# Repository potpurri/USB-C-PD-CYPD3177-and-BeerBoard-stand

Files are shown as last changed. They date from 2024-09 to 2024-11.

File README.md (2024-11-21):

# USB Power Delivery Board (CYPD-3177) / BeerBoard-stand

**THIS IS AN OLD DESIGN, FOR VER 2 LOOK AT [THIS REPOSITORY](https://github.com/potpurri/USB-C_PD_Board_V2_CYPD3177).**

This **USB Power Delivery (PD) Board** is based around the **CYPD-3177** chipset. The board allows users to select the desired output **voltage** and **current** using onboard switches, making it ideal for powering my **breadboard projects**. [Schematic can be found here.](https://github.com/potpurri/USB-C-PD-CYPD3177-and-BeerBoard-stand/blob/f3c342192d2ab72d846928ec36ac7f8050d37a6a/imgs/Schematic.pdf)

Users can choose between the following **voltage levels**: **5V, 9V, 12V, 15V, and 20V**, and **current levels**: **1A, 2A, 3A, 4A, and 5A**, depending on the configuration and power supply capabilities.

(The underside of the board also functions as a stand for the [BeerBoard](https://github.com/potpurri/BeerBoard))

The board is soldered by me using a [Pinecil V2](https://wiki.pine64.org/wiki/Pinecil) by PINE64  and [MHP50](https://e-design.com.cn/en/Mini-Hot-Plate-Preheater-MHP50-PG9555615) by MiniWare.

## Key Features
- Based on the **CYPD-3177** USB PD controller
- User-selectable output **voltage**: **5V, 9V, 12V, 15V, and 20V**
- User-selectable output **current**: **1A, 2A, 3A, 4A, and 5A**
- Supports standard USB Power Delivery profiles for flexible power output; compact and versatile

## Images

### Assembled Images
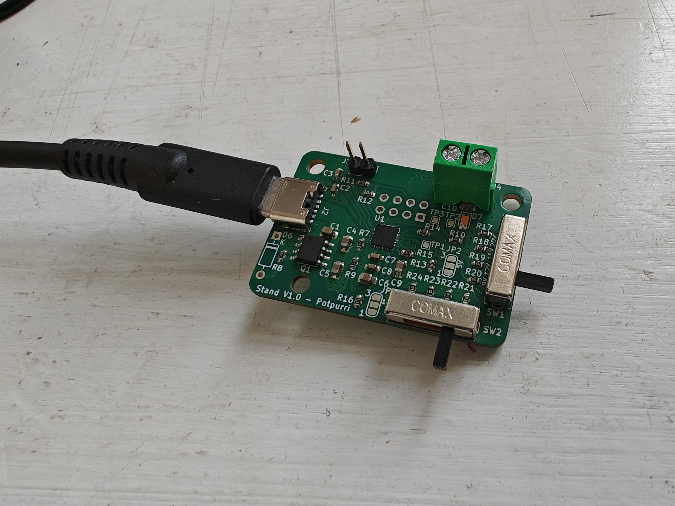
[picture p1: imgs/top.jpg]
USB PD Board

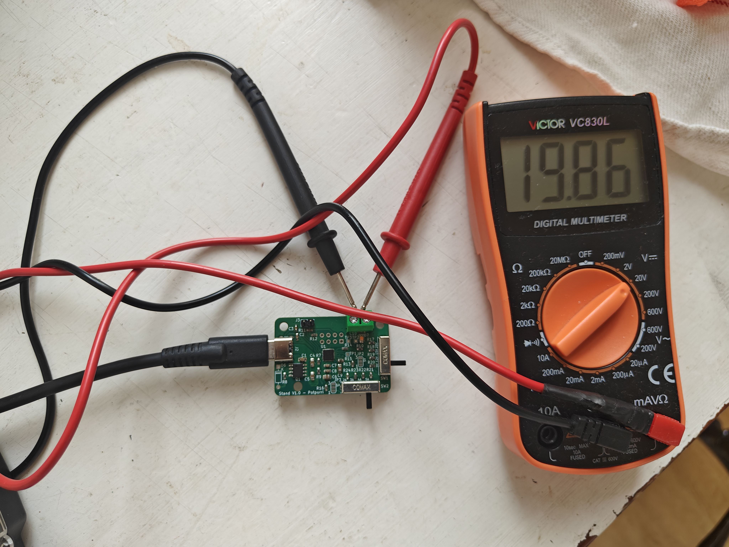
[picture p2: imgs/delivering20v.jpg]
20V delivery

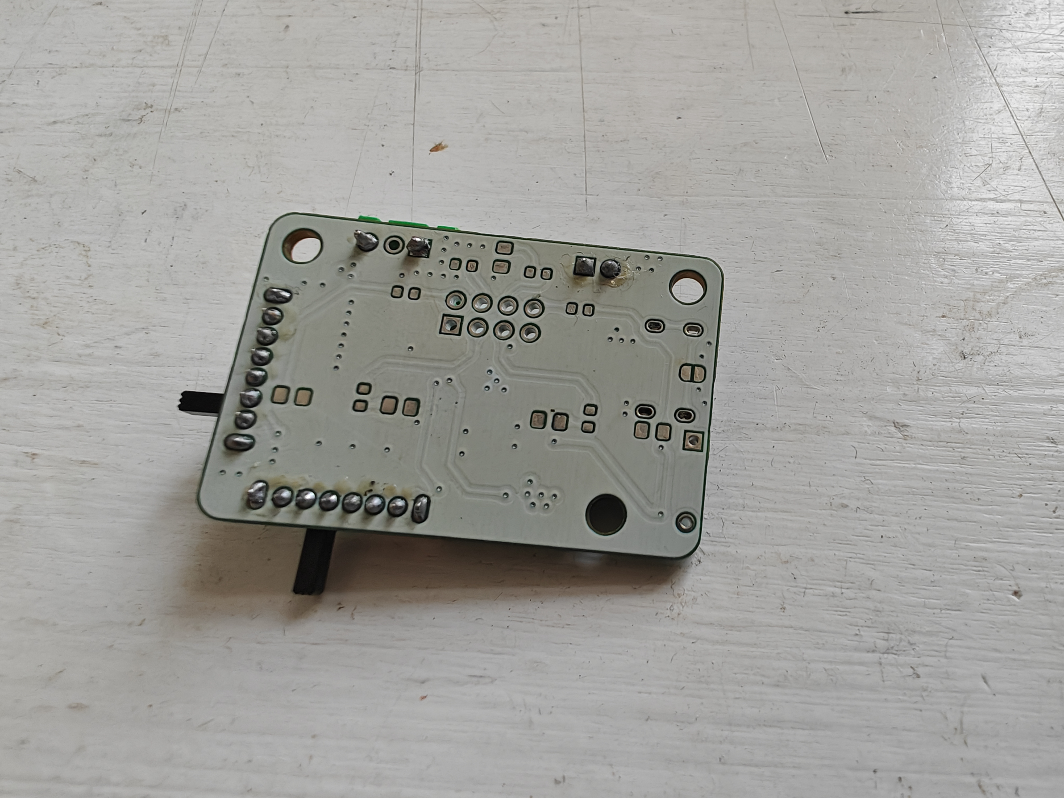
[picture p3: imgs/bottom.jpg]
Board bottom


### 3D Image
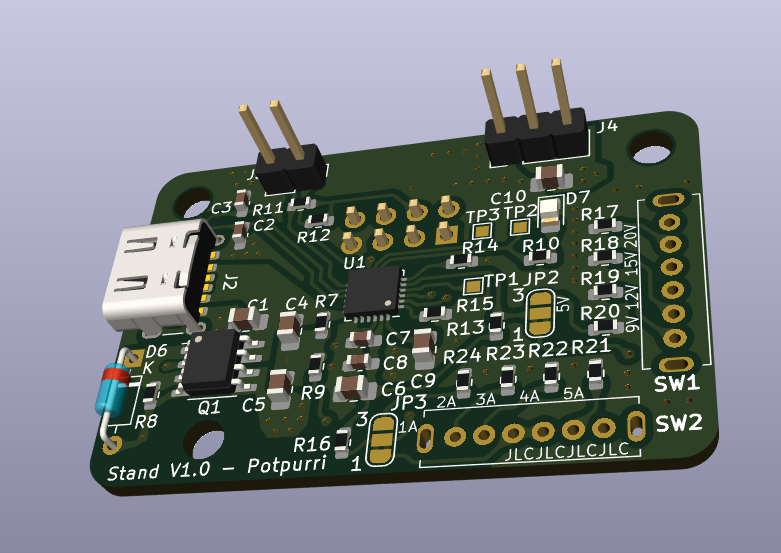
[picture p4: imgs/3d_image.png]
USB PD Board 3D Image


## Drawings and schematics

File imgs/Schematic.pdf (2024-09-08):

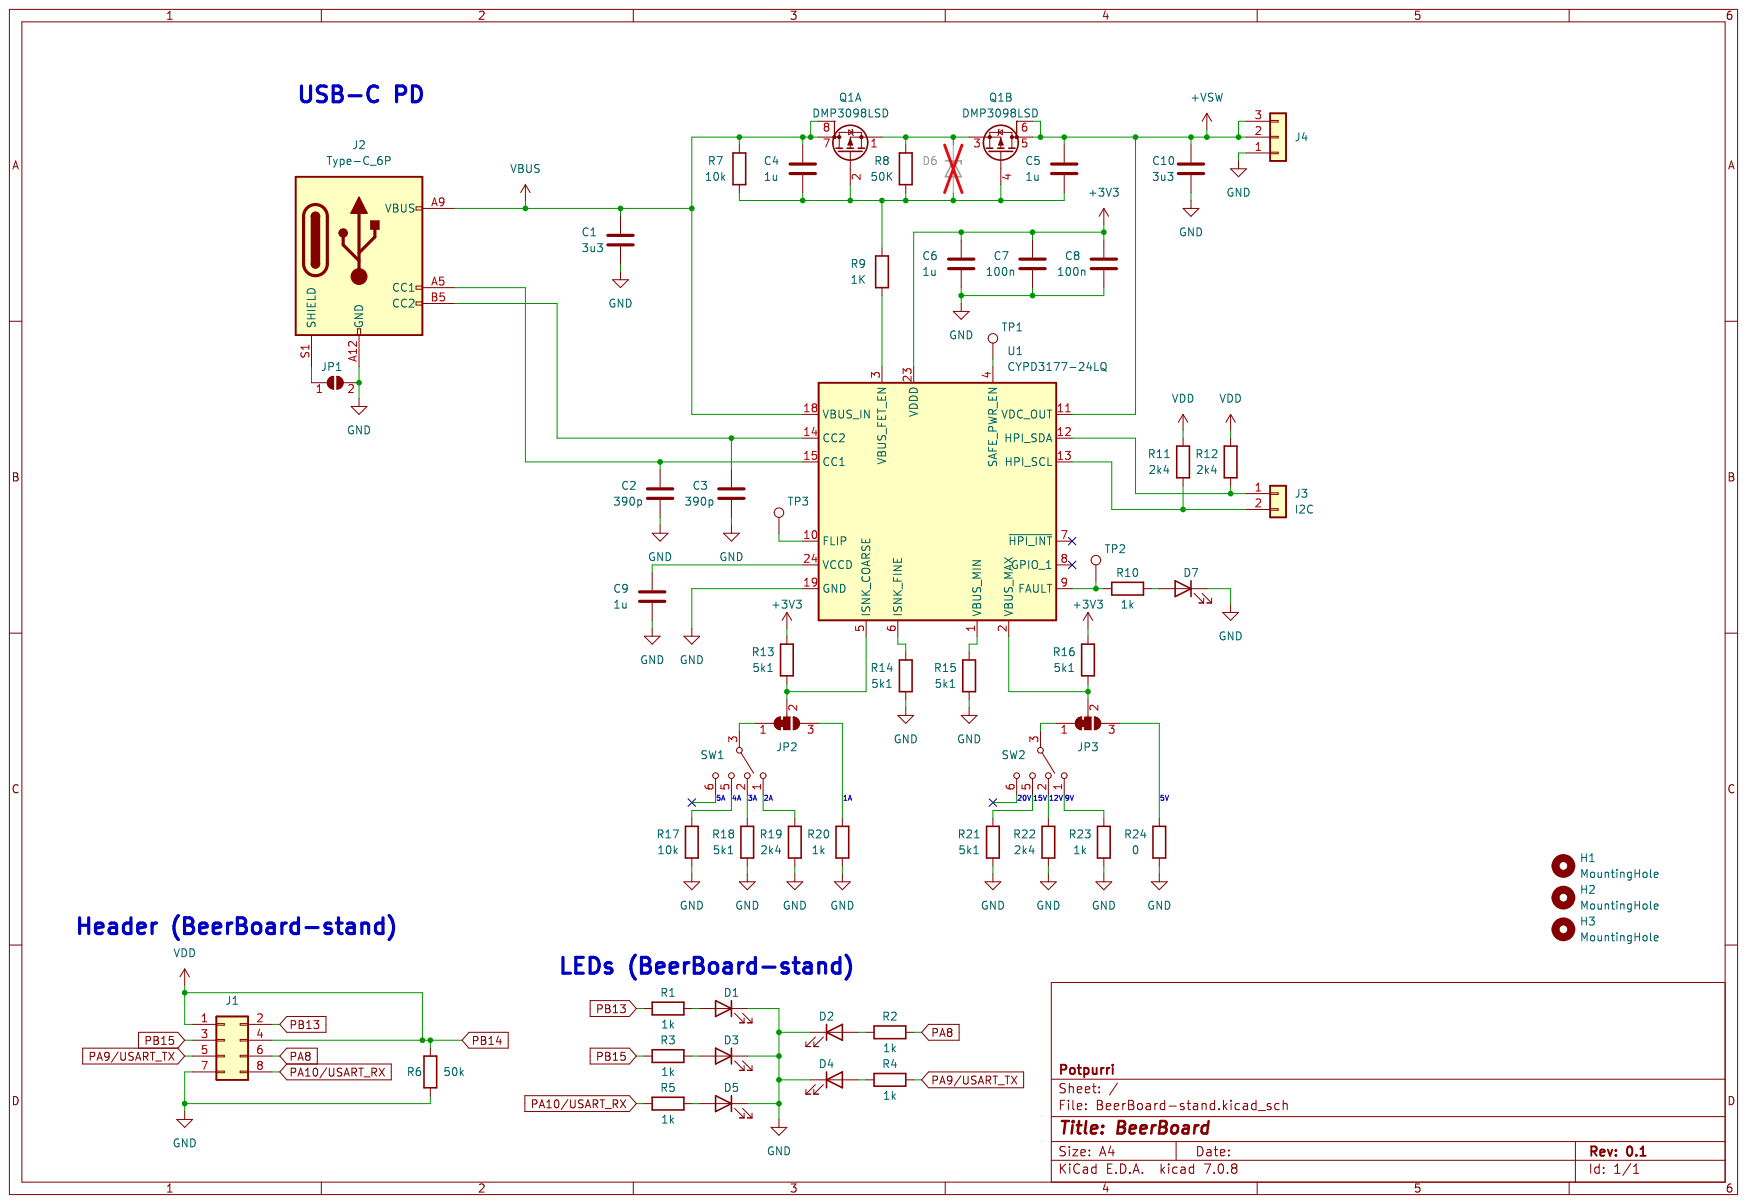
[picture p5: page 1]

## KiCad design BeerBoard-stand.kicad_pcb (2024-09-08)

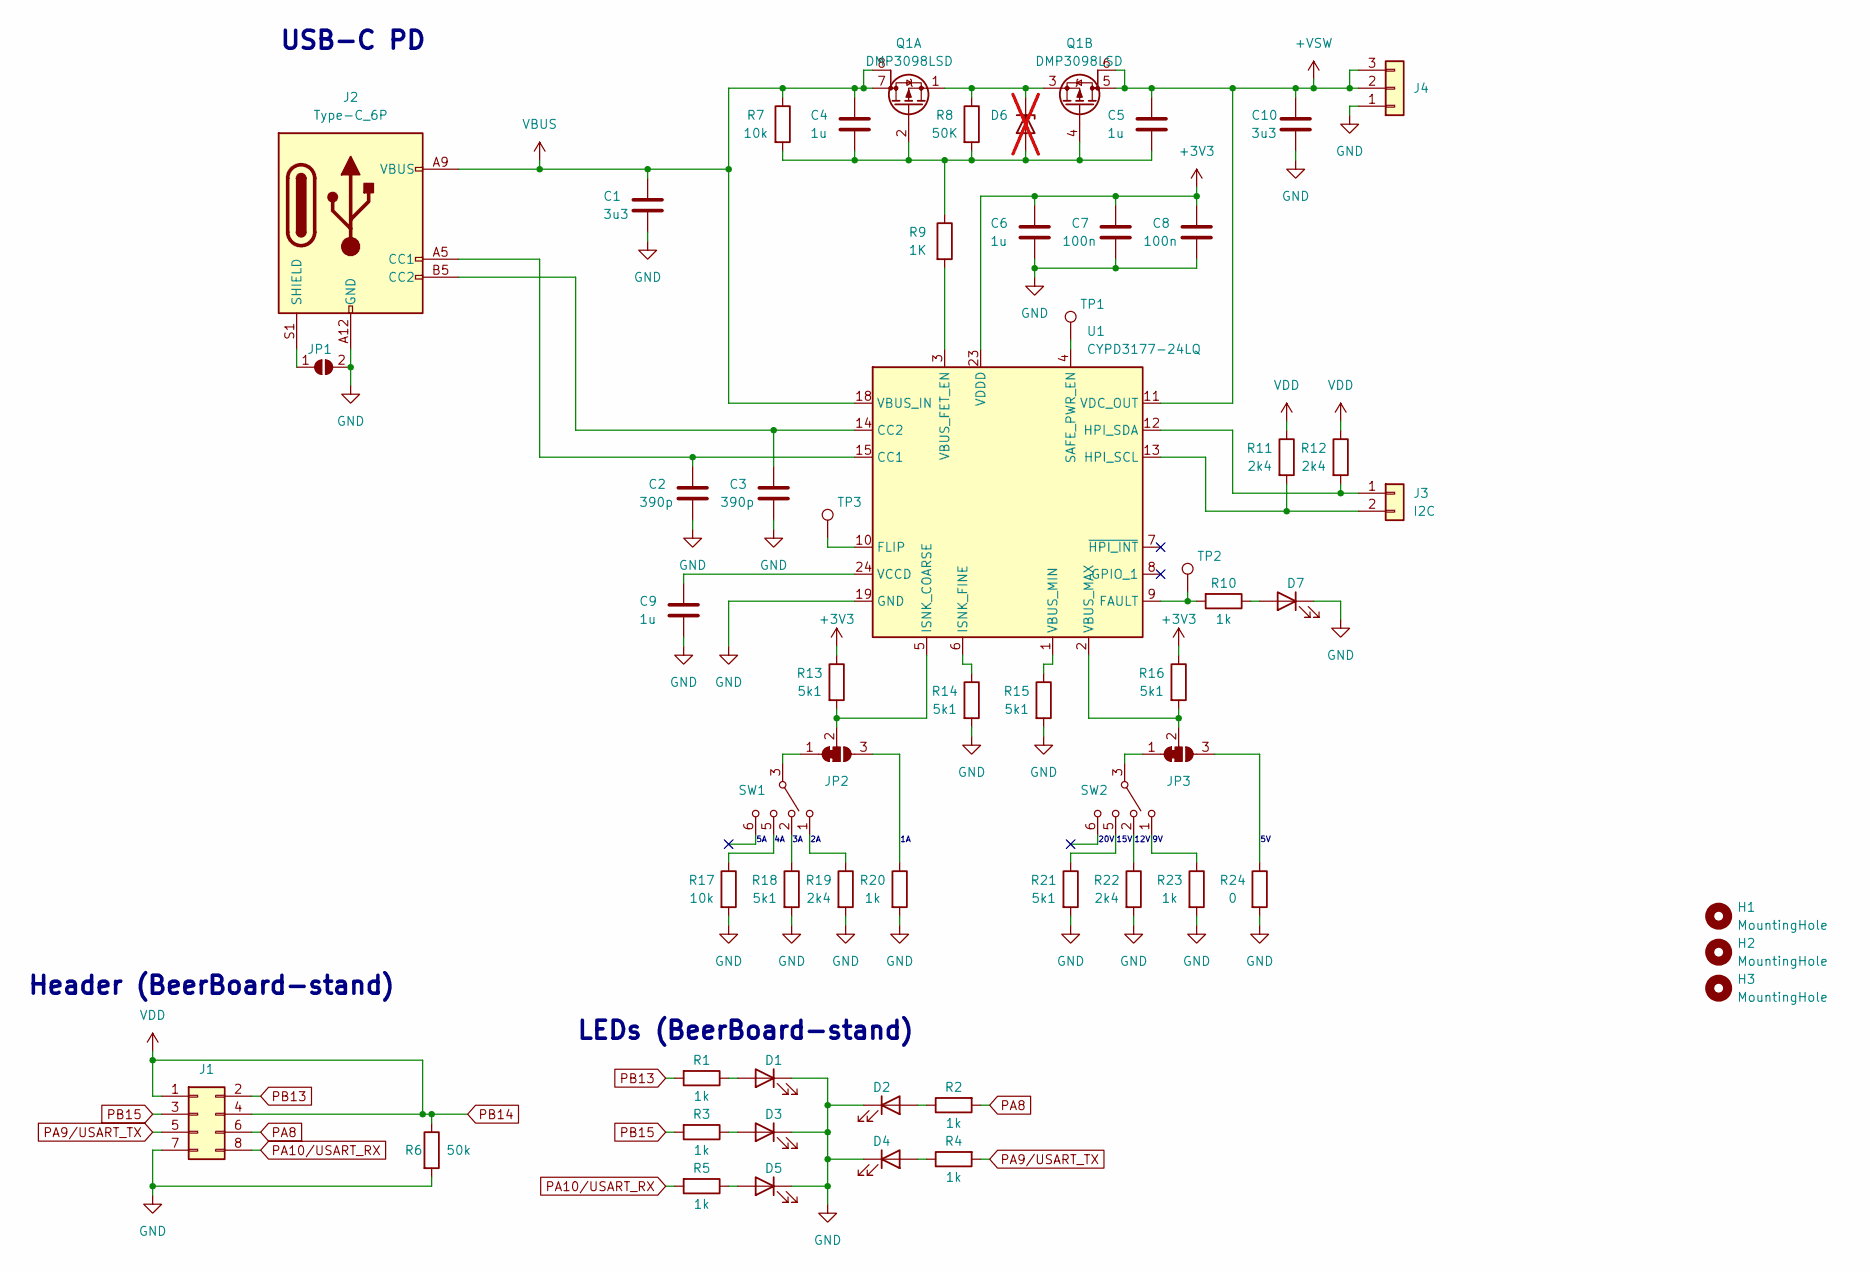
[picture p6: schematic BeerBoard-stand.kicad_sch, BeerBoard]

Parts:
C1, C10: 3u3; C_0805_2012Metric_Pad1.18x1.45mm_HandSolder
C2, C3: 390p; C_0603_1608Metric_Pad1.08x0.95mm_HandSolder
C4, C5, C6, C9: 1u; C_0805_2012Metric_Pad1.18x1.45mm_HandSolder
C7, C8: 100n; C_0603_1608Metric_Pad1.08x0.95mm_HandSolder
D1, D2, D3, D4, D5, D7: LED; LED_0805_2012Metric_Pad1.15x1.40mm_HandSolder
D6: D_Zener; D_DO-35_SOD27_P7.62mm_Horizontal; not fitted
H1, H2, H3: MountingHole; MountingHole_3.2mm_M3
J1: Conn_02x04_Odd_Even; PinHeader_2x04_P2.54mm_Vertical
J2: Type-C_6P; USB_C_Receptacle_GCT_USB4125-xx-x-0190_6P_TopMnt_Horizontal
J3: I2C; PinHeader_1x02_P2.54mm_Vertical
J4: Conn_01x03; PinHeader_1x03_P2.54mm_Vertical
JP1: SolderJumper_2_Open; SolderJumper-2_P1.3mm_Open_RoundedPad1.0x1.5mm
JP2, JP3: SolderJumper_3_Bridged12; SolderJumper-3_P1.3mm_Bridged2Bar12_RoundedPad1.0x1.5mm_Num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
Q1: DMP3098LSD; SOIC-8-1EP_3.9x4.9mm_P1.27mm_EP2.29x3mm
R1, R2, R3, R4, R5, R10, R20, R23: 1k; R_0603_1608Metric
R6: 50k; R_0603_1608Metric
R7, R17: 10k; R_0603_1608Metric
R8: 50K; R_0603_1608Metric
R9: 1K; R_0603_1608Metric
R11, R12, R19, R22: 2k4; R_0603_1608Metric
R13, R14, R15, R16, R18, R21: 5k1; R_0603_1608Metric
R24: 0; R_0603_1608Metric
SW1, SW2: SK-14D01-G 6
TP1, TP2, TP3: TestPoint; TestPoint_Pad_1.0x1.0mm
U1: CYPD3177-24LQ; QFN-24-1EP_4x4mm_P0.5mm_EP2.75x2.75mm

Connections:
+3V3: C6.1, C7.1, C8.1, R13.1, R16.1, U1.23 (VDDD)
+VSW: C5.1, C10.1, J4.2, J4.3, Q1.5 (D), Q1.6 (G), U1.11 (VDC_OUT)
CC1: C2.1, J2.A5 (CC1), U1.15 (CC1)
CC2: C3.1, J2.B5 (CC2), U1.14 (CC2)
GND: C1.2, C2.2, C3.2, C6.2, C7.2, C8.2, C9.2, C10.2, D1.1 (K), D2.1 (K), D3.1 (K), D4.1 (K), D5.1 (K), D7.1 (K), J1.7, J2.A12 (GND), J2.B12 (GND), J4.1, JP1.2 (B), R6.2, R14.2, R15.2, R17.2, R18.2, R19.2, R20.2, R21.2, R22.2, R23.2, R24.2, U1.19 (GND), U1.22 (GND), U1.25 (GND)
unnamed: D1.2 (A), R1.1
unnamed: D2.2 (A), R2.1
unnamed: D3.2 (A), R3.1
unnamed: D4.2 (A), R4.1
unnamed: D5.2 (A), R5.1
unnamed: C4.2, C5.2, D6.2 (A), Q1.2 (G), Q1.4 (G), R7.2, R8.2, R9.1
unnamed: D6.1 (K), Q1.1 (S), Q1.3 (S), R8.1
unnamed: D7.2 (A), R10.1
unnamed: J2.S1 (SHIELD), JP1.1 (A)
unnamed: J3.1, R12.2, U1.12 (HPI_SDA)
unnamed: J3.2, R11.2, U1.13 (HPI_SCL)
unnamed: JP2.1 (A), SW1.3, SW1.4
unnamed: JP2.3 (B), R20.1
unnamed: JP2.2 (C), R13.2, U1.5 (ISNK_COARSE)
unnamed: JP3.1 (A), SW2.3, SW2.4
unnamed: JP3.3 (B), R24.1
unnamed: JP3.2 (C), R16.2, U1.2 (VBUS_MAX)
unnamed: R17.1, SW1.5
unnamed: R18.1, SW1.2
unnamed: R19.1, SW1.1
unnamed: R21.1, SW2.5
unnamed: R22.1, SW2.2
unnamed: R23.1, SW2.1
unnamed: R10.2, TP2.1, U1.9 (FAULT)
unnamed: TP3.1, U1.10 (FLIP)
unnamed: R14.1, U1.6 (ISNK_FINE)
unnamed: TP1.1, U1.4 (SAFE_PWR_EN)
unnamed: R9.2, U1.3 (VBUS_FET_EN)
unnamed: R15.1, U1.1 (VBUS_MIN)
unnamed: C9.1, U1.24 (VCCD)
PA8: J1.6, R2.2
PA9/USART_TX: J1.5, R4.2
PA10/USART_RX: J1.8, R5.2
PB13: J1.2, R1.2
PB14: J1.1, J1.4, R6.1, R11.1, R12.1
PB15: J1.3, R3.2
VBUS: C1.1, C4.1, J2.A9 (VBUS), J2.B9 (VBUS), Q1.7 (D), Q1.8 (G), R7.1, U1.18 (VBUS_IN)

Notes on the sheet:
USB-C PD
Header (BeerBoard-stand)
15V
12V
LEDs (BeerBoard-stand)
20V

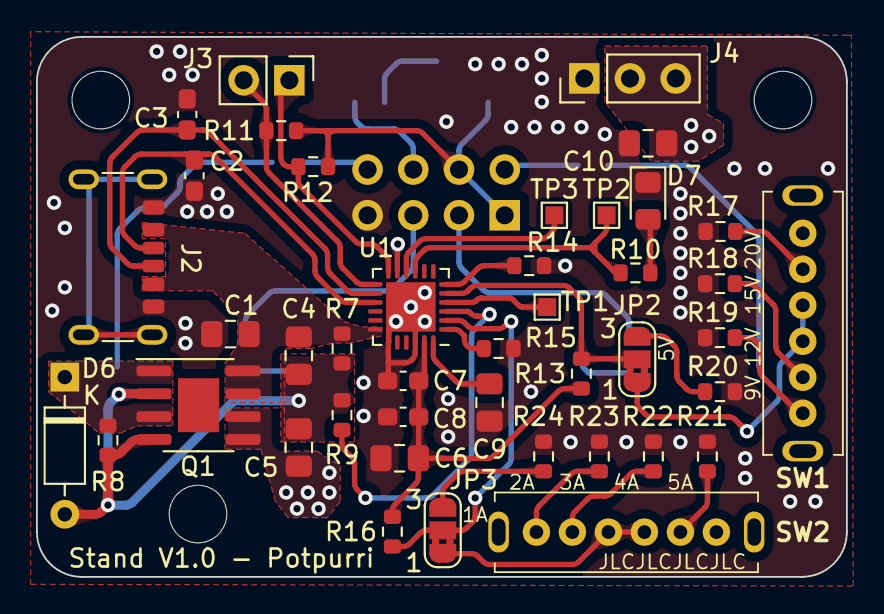
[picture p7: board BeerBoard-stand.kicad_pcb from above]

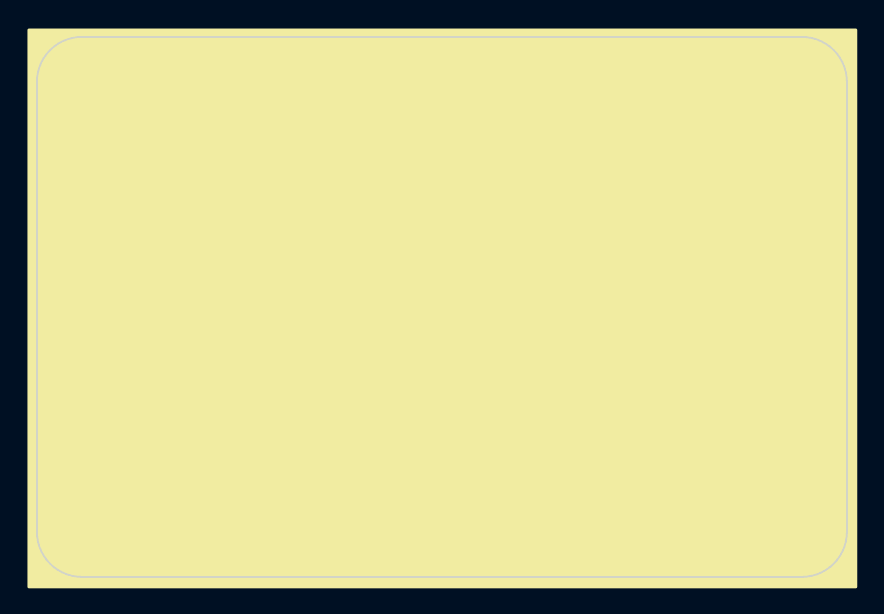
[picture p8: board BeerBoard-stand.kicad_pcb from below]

Board: 4 copper layers, 45.0 x 30.0 mm, 58 parts (13 on the bottom side), 42 nets.
